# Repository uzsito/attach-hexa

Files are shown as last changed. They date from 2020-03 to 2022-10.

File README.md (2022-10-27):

#  hexafan

## Description
This project is a configurable low-cost solution to produce fake cooling fan TACH signals for various computer systems. It consists of three main parts:
* Custom pcb with a few cheap components, mounting holes & socket for a replaceable microcontroller
* Arduino Nano or any clone with the same pinout
* Code running on Arduino to handle outputs in a flexible way

With the code uploaded to Arduino, a complete Attach-Hexa is able to drive six computer fan headers (channels) with TACH signals. Users can easily adjust the required RPM simulation on each channel, using pre-defined commands on serial interface.

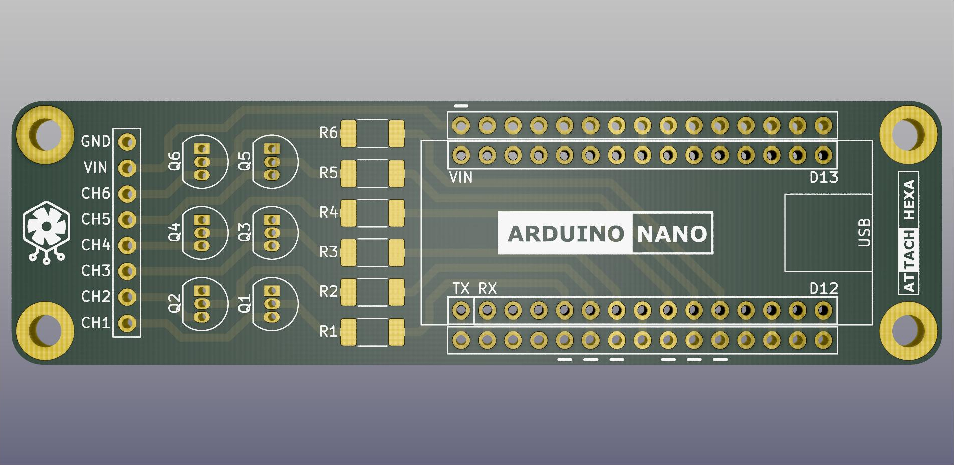
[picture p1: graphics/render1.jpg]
render1

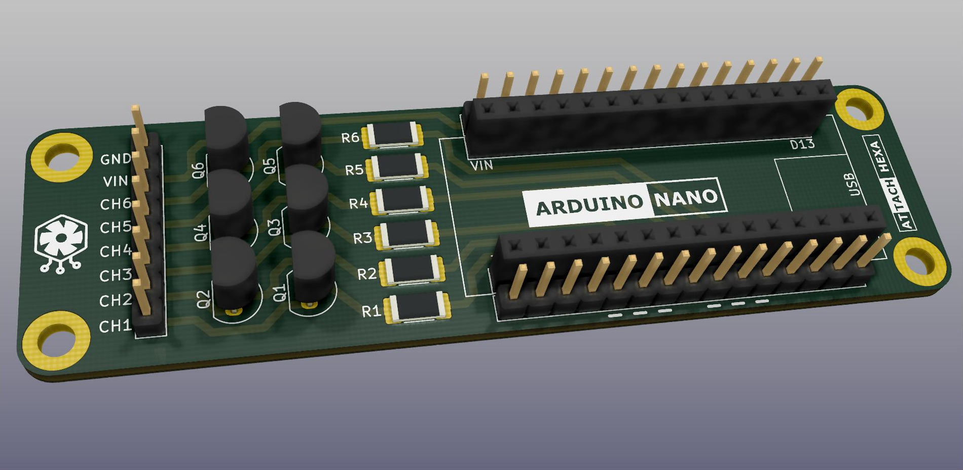
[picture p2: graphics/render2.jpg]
render2

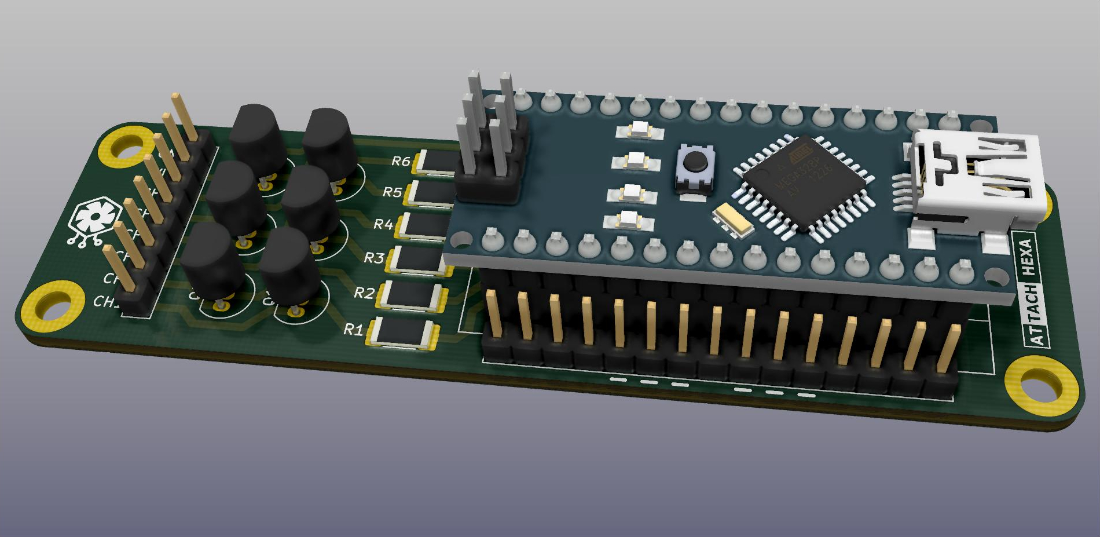
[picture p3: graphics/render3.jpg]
render3

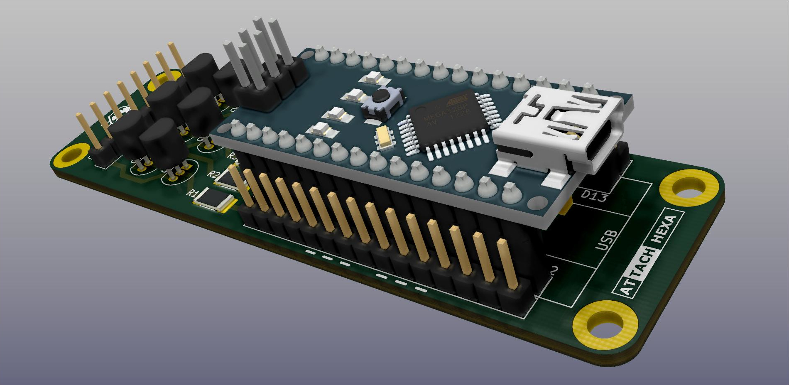
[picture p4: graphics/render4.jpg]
render4


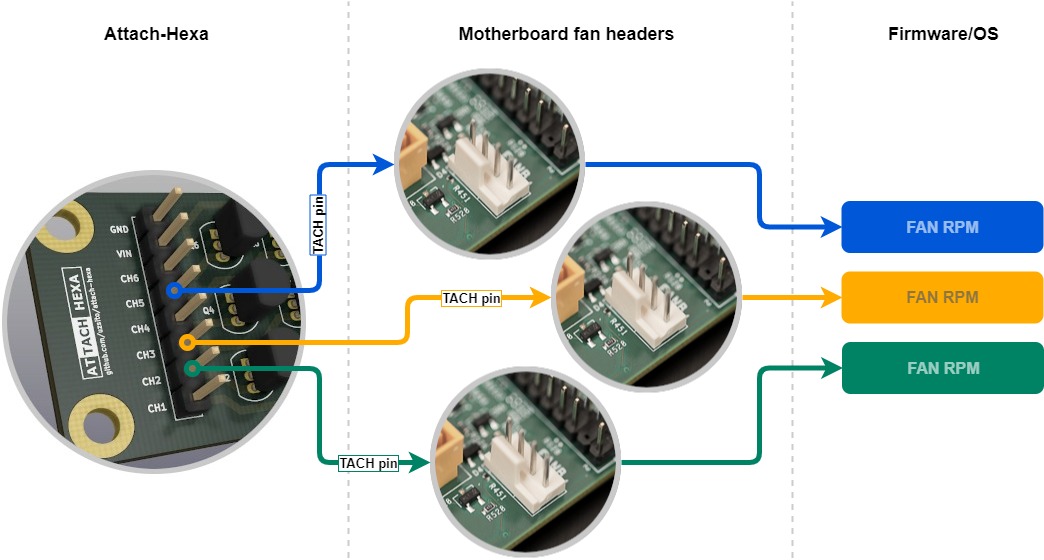
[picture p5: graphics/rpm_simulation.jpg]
rpm_simulation


## Do I need this?
If you have a conventional computer system with ordinary cooling, you don't. However, Attach-Hexa can be useful in the following cases:
* In passively cooled, modded enterprise systems (e.g. home lab), where elimination of "missing fan" alerts is needed to prevent undesired behaviour and ensure proper booting of the system (many servers do not boot at all, if fans are not present)
* In any system with water cooling, where RPM simulation is handy for tuning or testing the setup
* In PWM operation analysis, or other similar hardware development procedure
* In any other case, where generating square-waves is helpful

## Technical Details
TACH signals are used to report the current RPM of cooling fans to the system. Each fan has a dedicated pin for this purpose, usually in the following pinout:

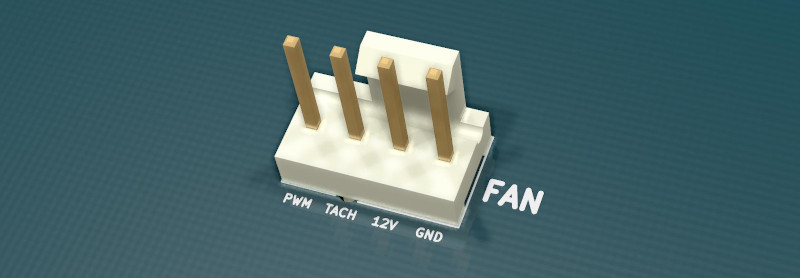
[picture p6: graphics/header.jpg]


On most motherboard headers, TACH pin is pulled high (+10-12V) by an internal pullup resistor. As the connected fan rotates, it's own built-in electronics (hall-effect sensor, transistor) pulls the TACH line to GND twice in every revolution. This results in a square-wave with a certain period, which is proportional to the fan's rotation speed. So if we would like to reproduce this, we have to pull that pin low at a specified rate. Arduino and similar microcontrollers can do that easily from code. The following schematic represents square-wave generation on channel 1:

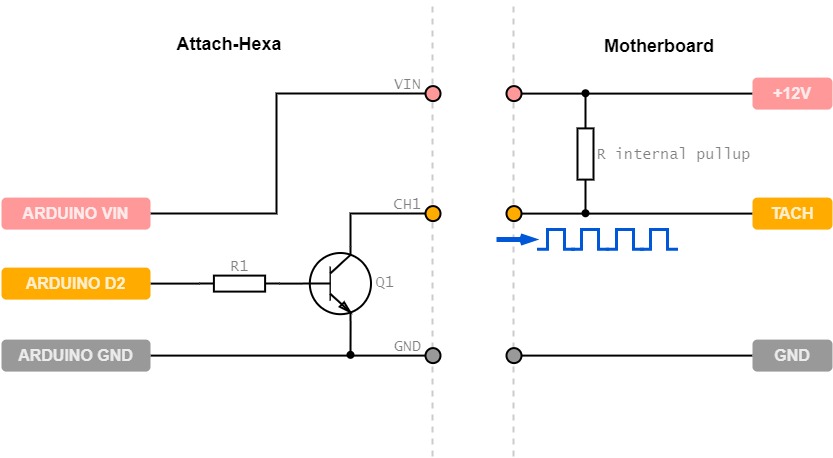
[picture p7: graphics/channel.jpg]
channel


The custom pcb board is holding the Arduino Nano, and makes it capable of pulling +12V (or more) lines safely through transistors. The entire unit can be powered from any fan header (using GND & VIN pins) up to +12V, or from USB. The power source is automatically selected to the highest voltage.

## Features
* Six simultaneously working channels
* Built-in LED can be linked to any channel as a visual tracker
* Desired RPMs, LED linked channel and LED frequency settings can be adjusted at runtime
* Serial interface listener to receive commands
* All settings can be saved to EEPROM to survive reboots
* Easily accessible Nano pin headers for potential new features, reserved pins marked on silkscreen

## PCB BOM
The PCB's size is 91mm * 26mm measured by PCBWAY's system. According to KiCAD it is 91,338mm * 25,87mm.

The following components are needed to assemble the custom pcb.

| Component  | Type | Package | Value | Quantity |
| --- | ---- | --- | ----- | --- |
| R1-R6 | Resistor | SMD-2010 | 4.7kΩ | 6 | 
| Q1-Q6 | Transistor | TO-92 | 2N3904 | 6 | 
| Pin header | Connector | 2.54mm single row | 8-pin male | 1 |
| Pin header | Connector | 2.54mm single row | 15-pin male | 2 |
| Pin socket | Connector | 2.54mm single row | 15-pin female | 2 |

Note: 2N3904 can handle collector current up to 10mA with base resistor 4.7kΩ by forced saturation (current flows from TACH pin to GND through transistor C-E). It is possible to substitute transistors with another type, but keep in mind you have to recalculate base resistor values in this case.

## Serial interface
You can manage Attach-Hexa over serial. Connect USB cable to Arduino, and use any terminal program with the following settings:
* Baud Rate: 115200 | Data: 8bit | Parity: none | Stop bits: 1bit | Flow control: none 
* Local echo: on | Send transmit marker: CR, LF or CR+LF 

Available commands:
* Set any channel RPM: `/channel 2 4000`
* Link LED to channel: `/led link 2`
* Adjust LED delay multiplier to get visible blinking: `/led multi 60`
* Print current settings to terminal: `/print`
* Save current settings to EEPROM: `/save`

| Command element  | Min | Max |
| --- | --- | --- |
| Channel number | 1 | 6 |
| Channel RPM | 1 | 32767 |
| LED link | 1 | 6 |
| LED multiplication | 1 | 255 |

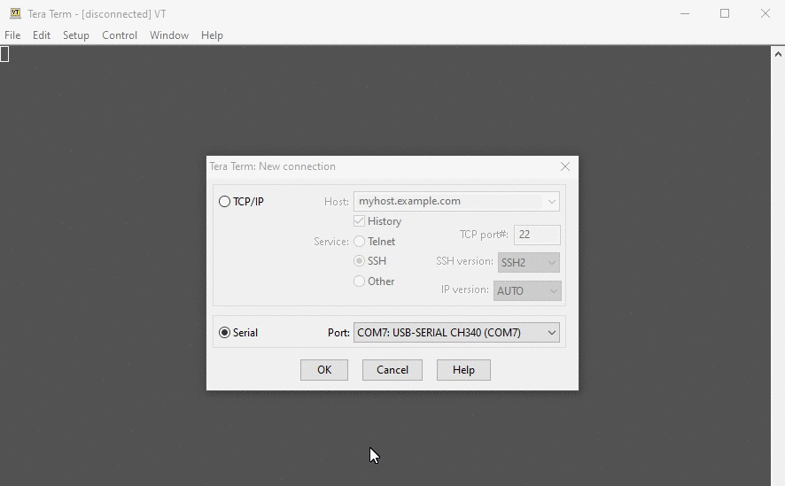
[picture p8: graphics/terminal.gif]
terminal


## Assembly and application
1. Clone or download this repository.
2. Use the prebuilt [gerber archive](kicad_board/gerber/attach_hexa.zip) to print the custom pcb. Any chinese manufacturer (JLPCB, ALLPCB, PCBWAY, etc.) can fabricate a copy for a couple dollars. Really, it's dirt cheap.
3. Once you got the pcb and the few listed components, assemble Attach-Hexa by hand soldering, no special tool needed.
4. Upload the [provided code](arduino_sketch/attach_hexa.ino) to an Arduino Nano using Arduino IDE (with [EEPROMex](https://github.com/thijse/Arduino-EEPROMEx) lib installed), and put the Nano in the socket.
5. Connect your terminal application to USB port and use the commands to achieve the desired settings. Save to EEPROM.
6. Place Hexa in the computer you would like to control, and make sure it is powered from that machine's USB port or fan header. Common GND is very important to pull TACH lines properly.
7. Attach channel pins to required TACH pins with dupont wires, and check the simulated RPM in the BIOS/UEFI or OS.

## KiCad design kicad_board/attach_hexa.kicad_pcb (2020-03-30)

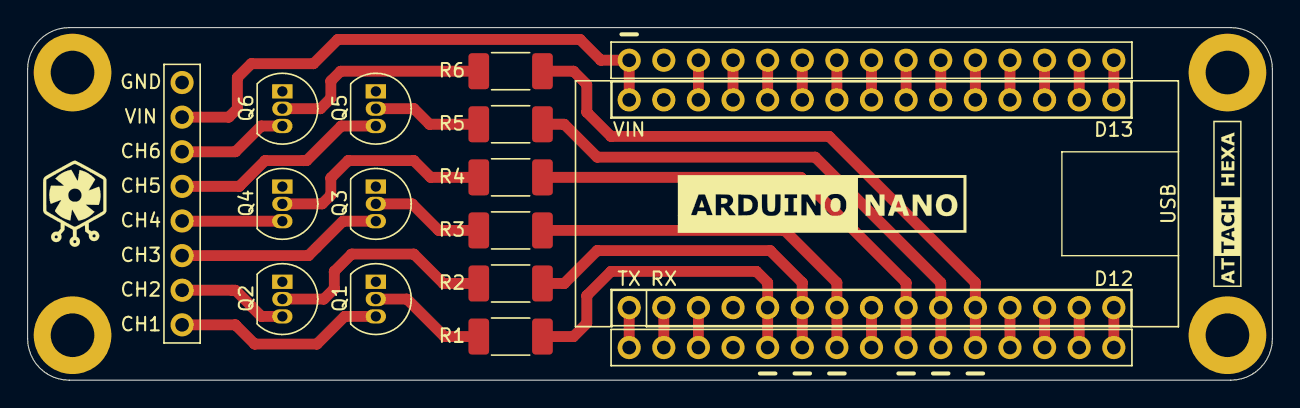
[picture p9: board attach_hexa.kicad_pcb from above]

Board: 2 copper layers, 91.3 x 25.9 mm, 22 parts (0 on the bottom side), 41 nets.

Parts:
A1: Arduino_Nano_v3.x; Arduino_Nano
H1, H2, H3, H4: MountingHole_Pad; MountingHole_3.2mm_M3_ISO7380_Pad
J1, J5: Conn_01x15_Male; PinHeader_1x15_P2.54mm_Vertical
J2: TACH; PinHeader_1x08_P2.54mm_Vertical
J3, J4: Conn_01x15; PinSocket_1x15_P2.54mm_Vertical
Q1, Q2, Q3, Q4, Q5, Q6: 2N3904; TO-92_Inline
R1, R2, R3, R4, R5, R6: 4,7k; R_2010_5025Metric_Pad1.52x2.65mm_HandSolder

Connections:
GND: A1.4, A1.29, H1.1, H2.1, H3.1, H4.1, J1.14, J2.8, J3.14, J4.4, J5.4, Q1.1, Q2.1, Q3.1, Q4.1, Q5.1, Q6.1
unnamed: A1.1, J4.1, J5.1
unnamed: A1.2, J4.2, J5.2
unnamed: A1.3, J4.3, J5.3
unnamed: A1.5, J4.5, J5.5, R1.2
unnamed: A1.6, J4.6, J5.6, R2.2
unnamed: A1.7, J4.7, J5.7, R3.2
unnamed: A1.8, J4.8, J5.8
unnamed: A1.9, J4.9, J5.9, R4.2
unnamed: A1.10, J4.10, J5.10, R5.2
unnamed: A1.11, J4.11, J5.11, R6.2
unnamed: A1.12, J4.12, J5.12
unnamed: A1.13, J4.13, J5.13
unnamed: A1.14, J4.14, J5.14
unnamed: A1.15, J4.15, J5.15
unnamed: A1.16, J1.1, J3.1
unnamed: A1.17, J1.2, J3.2
unnamed: A1.18, J1.3, J3.3
unnamed: A1.19, J1.4, J3.4
unnamed: A1.20, J1.5, J3.5
unnamed: A1.21, J1.6, J3.6
unnamed: A1.22, J1.7, J3.7
unnamed: A1.23, J1.8, J3.8
unnamed: A1.24, J1.9, J3.9
unnamed: A1.25, J1.10, J3.10
unnamed: A1.26, J1.11, J3.11
unnamed: A1.27, J1.12, J3.12
unnamed: A1.28, J1.13, J3.13
unnamed: A1.30, J1.15, J2.7, J3.15
unnamed: J2.1, Q1.3
unnamed: J2.2, Q2.3
unnamed: J2.3, Q3.3
unnamed: J2.4, Q4.3
unnamed: J2.5, Q5.3
unnamed: J2.6, Q6.3
unnamed: Q1.2, R1.1
unnamed: Q2.2, R2.1
unnamed: Q3.2, R3.1
unnamed: Q4.2, R4.1
unnamed: Q5.2, R5.1
unnamed: Q6.2, R6.1

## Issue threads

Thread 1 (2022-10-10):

Size of board?

Tall-Paul, 2022-10-10:
Hi, could you update the readme to include the size of the board (width * height)?  PCBWAY asks for this when requesting a PCB.

Cheers

uzsito, 2022-10-27:
> Hi, could you update the readme to include the size of the board (width * height)? PCBWAY asks for this when requesting a PCB.
>
> Cheers

Hello,

Of course, no problem. It is 91 mm* 26 mm according to my former PCBWAY orders (measured by their system).

From KiCAD, it seems it's 91,338 mm * 25,87 mm.

Readme updated.

Closed 2022-10-27.

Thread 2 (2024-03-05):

Scale the fake output to a real TACH input (but scaled)?

hongkongkiwi, 2024-03-05:
I'm very interested in using this code as a fan interceptor which scale a fans tach. I don't want to fake the output entirely, just scale it from a real fans output to something higher.

For example replacing a 3200rpm fan with a 2800rpm fan and have the software correctly read the out at different PWM.

Is this a feature in the current version? Or is the fan output 100% fake?

etomm, 2024-09-06:
This would be really interesting, more if in addition to the scale you would also be able to offset it.

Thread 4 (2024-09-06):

Reacting to a real PWM signal

etomm, 2024-09-06:
Would be really interesting if the project would be able to attach for each TACH channel a PWM input to regulate the channel according to it, specifying minimum rpm and maximum rpm.

This should help replace certain PSU fans.

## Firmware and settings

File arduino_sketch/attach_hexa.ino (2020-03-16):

//Attach Hexa - https://github.com/uzsito/attach-hexa
//Half Period (delay between switching states) calculation: 15000/RPM gives delay in millisecs.
//Channel logic is inverted: when a channel is LOW, the attached external TACH pin is HIGH

//Example serial commands:
//channel 1 2000
//channel 4 4500
//led link 2
//led multi 60

#include <EEPROMex.h>

int Channel_Rpms[6]; //RPMs for channels, integer size for easier EEPROM storage

unsigned long Channel_Delays[7]; //Calculated delays between switching states (half period of square wave) on channels

unsigned long When_State_Changed[7]; //Variables to store the last moment when channel states changed

const byte Channel_Pins[7] = {2, 3, 4, 6, 7, 8, LED_BUILTIN}; //Channel digital pin numbers: Channel 1-2-3-4-5-6-LED
unsigned long CurrentMicros; //Variable for time measurement

byte LED_Linked_Channel; //Link built-in indicator LED to desired channel
byte LED_Delay_Multiplier; //Multiplies LED delay to make visible results

char Command_First[8]; //Serial command handler variables
char Command_Second[6];
byte Command_Second_Num;
unsigned int Command_Third;

const byte Number_Of_Chars = 20; //Serial receiver variables
char Received_Chars[Number_Of_Chars];
boolean Serial_New_Data = false;
boolean Serial_Listening_Printed = false;

char Read_Char; //Variable to load chars from serial buffer (ASCII bytes, one-by-one)
static byte Char_Stepper = 0;
char * Char_Index; //Pointer to locate delimeter

char Command_Start_Char = '/'; //Markers to identify start & end of commands
char Command_End_Char = '\r'; //CR - Carriage Return
char Command_End_Char2 = '\n'; //LF - Line Feed

static boolean Receive_In_Progress = false; //Sets true if command start char catched

int address_LED_Link; //EEPROM addresses
int address_LED_Multi;
int address_Channel_Rpms;

void setup() {
  Serial.begin(115200);

  Read_EEPROM(); //Load settings from EEPROM to variables
  Update_Delays(); //Set delays to use in channel handling

  Serial.println("Attach Hexa running. More info: https://github.com/uzsito/attach-hexa");
  Serial.println("Completed loading settings from EEPROM.");

  Print_Settings();

  pinMode(Channel_Pins[0], OUTPUT); //Channel 1
  pinMode(Channel_Pins[1], OUTPUT); //Channel 2
  pinMode(Channel_Pins[2], OUTPUT); //Channel 3
  pinMode(Channel_Pins[3], OUTPUT); //Channel 4
  pinMode(Channel_Pins[4], OUTPUT); //Channel 5
  pinMode(Channel_Pins[5], OUTPUT); //Channel 6
  pinMode(Channel_Pins[6], OUTPUT); //Channel tracker LED
}

void loop() {
  CurrentMicros = micros();

  Channel_Handler();
  Serial_Receiver();
  Serial_Command_Handler();
}

void Channel_Handler () { //Handle pin states when appropriate delay passed

  int i = 0;

  do { //Check all channels

    if (CurrentMicros - When_State_Changed[i] >= Channel_Delays[i]) {

      //delay passed, read state of pin and change it

      switch (digitalRead(Channel_Pins[i])) { //Yes, we read an output pin! Returns binary state
        case 0:
          digitalWrite(Channel_Pins[i], HIGH);
          break;

        case 1:
          digitalWrite(Channel_Pins[i], LOW);
          break;
      }

      When_State_Changed[i] += Channel_Delays[i];  //save time when state change SHOULD be made, this provides more accuracy than saving current time
    }

    i++;

  } while (i <= 6);
}

void Serial_Receiver() { //Handle serial received data, listening for commands

  if (Serial_Listening_Printed == false) { //Inform user about serial listening only once.
    Serial.println("Listening to serial commands.");
    Serial_Listening_Printed = true;
  }

  while (Serial.available() > 0 && Serial_New_Data == false) { //Start to examine chars only if serial buffer is not empty, and previous segment already parsed
    Read_Char = Serial.read(); //Examine chars in serial buffer, one per iteration

    //Skips all the following if first character is not command start char (marker)

    if (Receive_In_Progress == true) { //Command start char found, start receiving procedure until command end char captured
      if (Read_Char != Command_End_Char && Read_Char != Command_End_Char2) {
        Received_Chars[Char_Stepper] = Read_Char;
        Char_Stepper++;
        if (Char_Stepper >= Number_Of_Chars) {
          Char_Stepper = Number_Of_Chars - 1;
        }
      }
      else {
        Received_Chars[Char_Stepper] = '\0'; //Command end char found, terminate receiving and insert null character
        Receive_In_Progress = false;
        Char_Stepper = 0;
        Serial_New_Data = true; //Received data is ready to parse, skip next iteration
      }
    }

    else if (Read_Char == Command_Start_Char) { //If command start char found, start receiving procedure
      Receive_In_Progress = true;
    }
  }
}

void Serial_Command_Handler() { //Parse serial data, execute received commands

  if (Serial_New_Data == true) {

    Char_Index = strtok(Received_Chars, " "); //Fill pointer with delimeter position
    strcpy(Command_First, Char_Index); //Get all chars to char array until pointer position

    Char_Index = strtok(NULL, " "); //Find next delimeter in previous source
    strcpy(Command_Second, Char_Index); //Get all chars to char array until pointer
    Command_Second_Num = byte(atoi(Char_Index)); //Also convert to number and store in a byte

    Char_Index = strtok(NULL, " "); //Find next delimeter in previous source
    Command_Third = atoi(Char_Index); //Get all chars and convert to int until pointer

    if (strcmp(Command_First, "channel") == 0 && Command_Second_Num >= 1 && Command_Second_Num <= 6 && Command_Third >= 1 && Command_Third <= 32767) { //valid channel rpm modification command
      Channel_Rpms[Command_Second_Num - 1] = Command_Third; //Update RPM data
      Update_Delays(); //Update all delays to use in channel handling, based on RPM data
      Serial.print("Channel "); Serial.print(Command_Second_Num); Serial.print(" RPM changed to "); Serial.println(Channel_Rpms[Command_Second_Num - 1]);
    }
    else if (strcmp(Command_First, "led") == 0 && strcmp(Command_Second, "link") == 0 && Command_Third >= 1 && Command_Third <= 6) { //valid led link command
      LED_Linked_Channel = Command_Third;
      Channel_Delays[6] = ((Channel_Delays[LED_Linked_Channel - 1]) * LED_Delay_Multiplier); //Update LED delay based on linked channel and multiplier
      Serial.print("LED linked to channel "); Serial.println(LED_Linked_Channel);
    }
    else if (strcmp(Command_First, "led") == 0 && strcmp(Command_Second, "multi") == 0 && Command_Third >= 1 && Command_Third <= 255) { //valid led delay multiplication command
      LED_Delay_Multiplier = Command_Third;
      Channel_Delays[6] = ((Channel_Delays[LED_Linked_Channel - 1]) * LED_Delay_Multiplier); //Update LED delay based on linked channel and multiplier
      Serial.print("LED delay multiplication changed to "); Serial.println(LED_Delay_Multiplier);
    }
    else if (strcmp(Command_First, "print") == 0 && Command_Second[0] == 0) { //valid print command
      Print_Settings();
    }

    else if (strcmp(Command_First, "save") == 0 && Command_Second[0] == 0) { //save all settings to EEPROM

      EEPROM.updateByte(address_LED_Link, LED_Linked_Channel); //Update saved data only if there is a difference
      EEPROM.updateByte(address_LED_Multi, LED_Delay_Multiplier);
      EEPROM.updateBlock<int>(address_Channel_Rpms, Channel_Rpms, 6);

      Serial.println("Current settings saved to EEPROM.");
    }

    else {
      Serial.println("Unknown request. Please check available commands at: https://github.com/uzsito/attach-hexa");
    }

    Serial_New_Data = false; //Received data parsed, allow Serial_Receiver function to capture chars again
  }
}

void Print_Settings() { //Print current settings

  Serial.print("LED Linked Channel: "); Serial.println(LED_Linked_Channel);
  Serial.print("LED Delay Multiplier: "); Serial.println(LED_Delay_Multiplier);

  for (int i = 0; i <= 5; i++) {
    Serial.print("Channel "); Serial.print(i + 1); Serial.print(" RPM: "); Serial.print(Channel_Rpms[i]); Serial.println(" rpm."); //Print channel RPMs and delays
    Serial.print("Channel "); Serial.print(i + 1); Serial.print(" Delay: "); Serial.print(Channel_Delays[i]); Serial.println(" usec.");
  }
  Serial.print("LED Delay: "); Serial.print(Channel_Delays[6]); Serial.println(" usec.");;
}

void Read_EEPROM() { //Load settings from EEPROM to variables

  EEPROM.setMemPool(0, EEPROMSizeATmega328); //EEPROM used space (starting & end address)

  address_LED_Link = EEPROM.getAddress(sizeof(byte)); //set available EEPROM addresses based on stored data size
  address_LED_Multi = EEPROM.getAddress(sizeof(byte));
  address_Channel_Rpms = EEPROM.getAddress(sizeof(int) * 6);

  LED_Linked_Channel = EEPROM.read(address_LED_Link); //read saved data from EEPROM
  LED_Delay_Multiplier = EEPROM.read(address_LED_Multi);
  EEPROM.readBlock<int>(address_Channel_Rpms, Channel_Rpms, 6);
}

void Update_Delays() { //Update all delays to use in channel handling, based on RPM data
  for (int i = 0; i <= 5; i++) {
    Channel_Delays[i] = (15000000 / Channel_Rpms[i]); //Update all calculated channel delays from RPMs
  }
  Channel_Delays[6] = ((Channel_Delays[LED_Linked_Channel - 1]) * LED_Delay_Multiplier); //Update calculated LED delay from linked channel data
}

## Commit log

2020-03-16 Arduino Sketch
2020-03-16 KiCad Project
    [attach_hexa.kicad_pcb, attach_hexa.sch]
2020-03-23 Changed SMD sizes to ease hand soldering. Improved silkscreen visibility.
    [attach_hexa.kicad_pcb, attach_hexa.sch]
2020-03-24 Minor trace routing, positioning and silkscreen adjustments
    [attach_hexa.kicad_pcb]
2020-03-24 Set base resistors to 4.7k - force transistor saturation up to 10mA collector current
    [attach_hexa.kicad_pcb, attach_hexa.sch]
2020-03-25 Channel schematic
2020-03-30 Updated silkscreen
    [attach_hexa.kicad_pcb]
2020-05-12 Upload gerber files
    [attach_hexa-B_Cu.gbr, attach_hexa-B_Mask.gbr, attach_hexa-B_SilkS.gbr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]
